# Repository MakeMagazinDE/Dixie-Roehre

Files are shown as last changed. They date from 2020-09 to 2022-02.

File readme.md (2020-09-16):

GitHub Logo

Maker Media GmbH
*** 

# Dixie-Röhre
TFT-Displays im Stil von Nixie-Röhren

### Dieser „Röhre“ dienen kleine TFT-Displays als Basis

Die „Dixie-Röhren“ werden mit einem Arduino Nano als Uhr betrieben. Sie sind in ein Holzgehäuse im Retrostil gebaut, in dem auch die überschaubare Steuerelektronik Platz findet. Zum Einstellen der Uhr sind drei Taster eingebaut. Mit einem SD-Karten-Shield und einer SD-Karte lassen sich die Bilder austauschen und für die Spannungsversorgung der Displays ist noch ein Spannungsregler nötig.

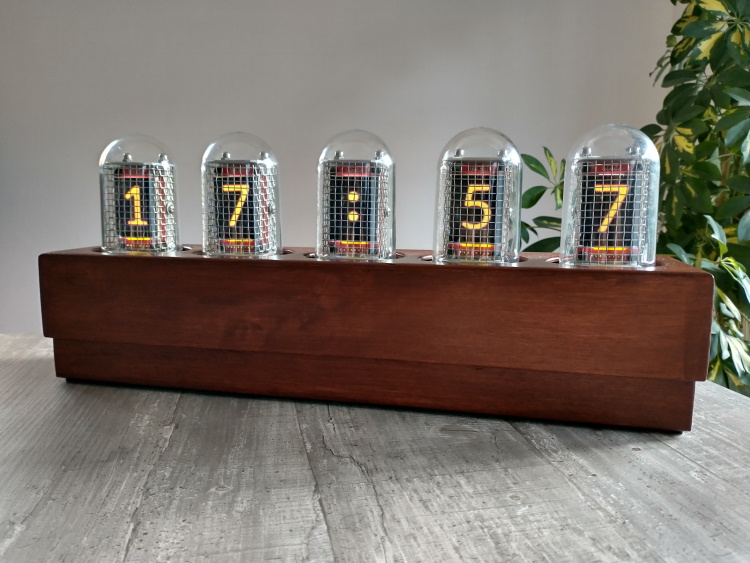
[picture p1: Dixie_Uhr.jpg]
 

Den vollständigen Artikel mit der Bauanleitung gibt es in der [Make-Ausgabe 5/2020](https://www.heise.de/select/make/2020/5/seite-46) zu lesen.

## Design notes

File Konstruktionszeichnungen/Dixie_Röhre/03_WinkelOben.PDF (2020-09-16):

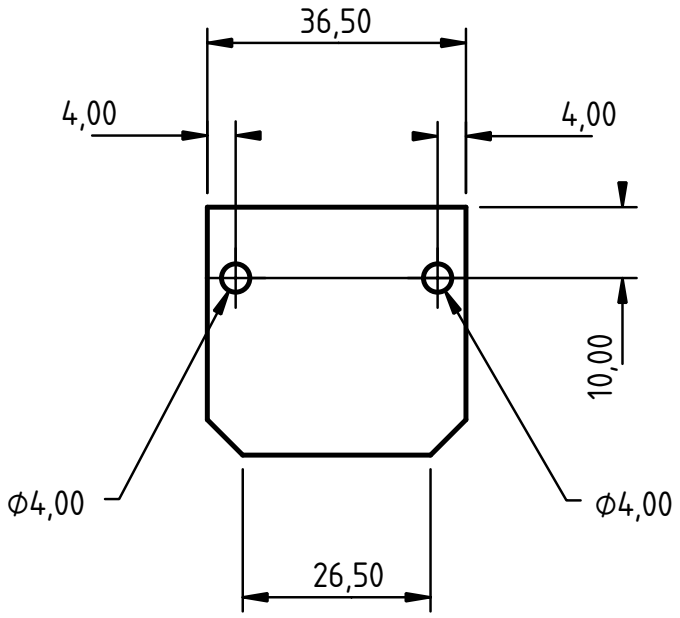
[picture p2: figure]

3

0,0

0

3

5,0

0

20,00

# Dixie-Röhre

Material: Aluminium-Winkelprofil 20mmx35mm Stärke 2mm

# 1 Stück Winkel Oben

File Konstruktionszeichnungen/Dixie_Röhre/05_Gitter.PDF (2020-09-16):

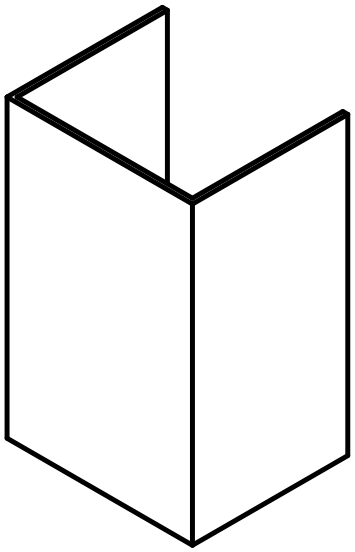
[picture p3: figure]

# Dixie-Röhre

# Gitter

Material: Drahtgitter Stärke 1mm

## 1 Stück

5

9,0

0

31,00 | 37,00

35,00

3

0,0

0

3

1,0

0

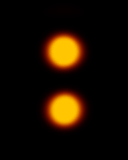
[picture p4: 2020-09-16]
Software/SD_Card_Pictures/DOT.bmp

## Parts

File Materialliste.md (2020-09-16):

# Dixie-Röhren

## Materialliste

### Material für eine Röhre
- [ ] 1× [Kunststoff-Glocke mit Untersetzer](https://www.opitec.de/basics/floristik/gefaesse/kunststoff--/kunststoff-glocke-mit-untersetzer-67-x-102-mm.html) 67 × 102mm 
- [ ] Acryl-Buntlack, Farbe: grau
- [ ] 2×  [Aluminium Quadratrohr](https://www.bauhaus.info/metallprofile-kunststoffprofile/kantoflex-quadratrohr/p/10521778) 7,5mm × 7,5mm, Stärke 1mm; 60mm lang
- [ ] 2× [Aluminium Winkelprofil](https://www.bauhaus.info/metallprofile-kunststoffprofile/kantoflex-winkelprofil/p/10520119) 20mm ×35mm, Stärke 2mm; 36,5mm lang                                  
- [ ] 2× Gewindestange M4; 90mm lang 
- [ ] 4× Mutter M4
- [ ] 2× Hutmutter M4
- [ ] 2× Federscheibe M4
- [ ] 2× Unterlegscheibe M4
- [ ] 4× [Nylon-Abstandshalter M3](https://www.amazon.de/gp/product/B00W79JXFA/), 7mm
- [ ] 4× Nylon-Schrauben M3
- [ ] 1× [SPI TFT Display 1,8 Zoll](https://www.amazon.de/gp/product/B078J5TS2G/) mit 128 × 160 Pixeln, ST7735 Bildcontroller
- [ ] 8× Farbige Kupferlitze, Querschnitt ca. 0,14 mm²; ca. 100mm lang
- [ ] 8× [Büschel/Bananen-Stecker](https://www.amazon.de/gp/product/B07S6MVTNQ/), 4mm
- [ ] 1× [Drahtgitter](https://www.amazon.de/gp/product/B07ZSS4ZQ6/), ca. 59mm × 93mm 
- [ ] 2× Unterlegscheibe M3
- [ ] 2× Schraube M3x4mm

### Elektronik
- [ ] 1× [Steckbrett mit „Jumper“-Kabeln](https://www.amazon.de/dp/B07NJ3FX25/)
- [ ] 1× Arduino Nano
- [ ] 1× [Arduino SD-Karten Shield](https://www.amazon.de/gp/product/B077MB17JB/) 
- [ ] SD-Karte (FAT32-formatiert)
- [ ] 1× Lochrasterplatine 2,54mm, 7×5 cm 
- [ ] Kupferdraht, verzinnt; Stärke ca. 0,4mm; 
- [ ] Stiftleisten und Buchsenleisten im Raster 2,54mm
- [ ] 6× Widerstände 10k
- [ ] 3× Kondensator 10nF; Elektrolytkondensatoren 1× 100nF und 1× 10µF 
- [ ] 1× Spannungsregler 3,3V (LD33V)
- [ ] 3× [Drucktaster mit Schließer-Kontakt](https://www.amazon.de/gp/product/B07Q6YPST6/)
- [ ] 1× USB-B Buchse
- [ ] 40× [Buchsen für Bananen-Stecker](https://www.amazon.de/gp/product/B07VWQQRHC/)

### Gehäuse
- [ ] Sperrholzplatten (Größe min. A3)
- [ ] Vierkanthölzer (ca. 9x9mm)
- [ ] Holzleim 
- [ ] Möbelversiegelung oder Buntlack, Farbe: z.B. Teak

## Werkzeug
- [ ] Metallsäge
- [ ] Laubsäge
- [ ] Feile(n) und Schleifpapier
- [ ] Akkuschrauber oder Bohrmaschine, Bohrer 
- [ ] Kegel-Senker und ein M3 Gewindeschneider, Flach-Senker (oder Forstnerbohrer)
- [ ] Schraubstock, Schraubzwingen
- [ ] Lötkolben
- [ ] Diverse Handwerkzeuge (Seitenschneider, Schraubendreher, Ringschlüssel)
- [ ] Teppichmesser oder Cutter-Messer
- [ ] Durchgangsprüfer oder Handmultimeter

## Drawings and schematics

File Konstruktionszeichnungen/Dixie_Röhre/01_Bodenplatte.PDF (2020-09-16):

# Dixie-Röhre

# 1 Stück

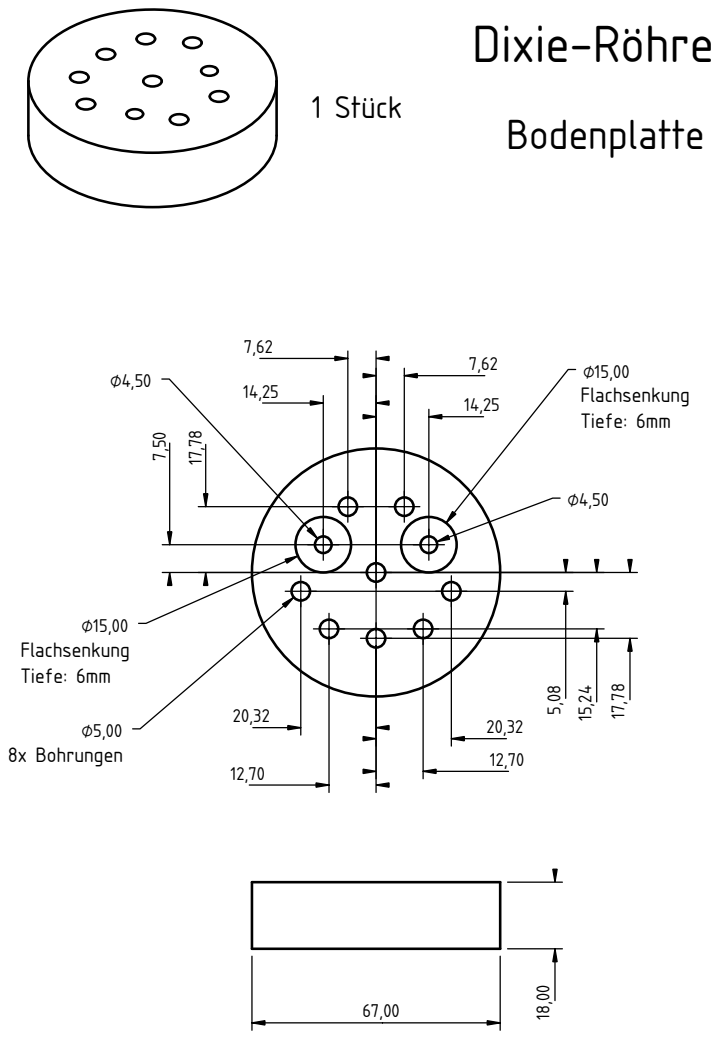
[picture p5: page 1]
Flachsenkung Tiefe: 6mm; 8x Bohrungen; Bodenplatte

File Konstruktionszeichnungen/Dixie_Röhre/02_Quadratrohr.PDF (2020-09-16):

# Dixie-Röhre

## 2 Stück

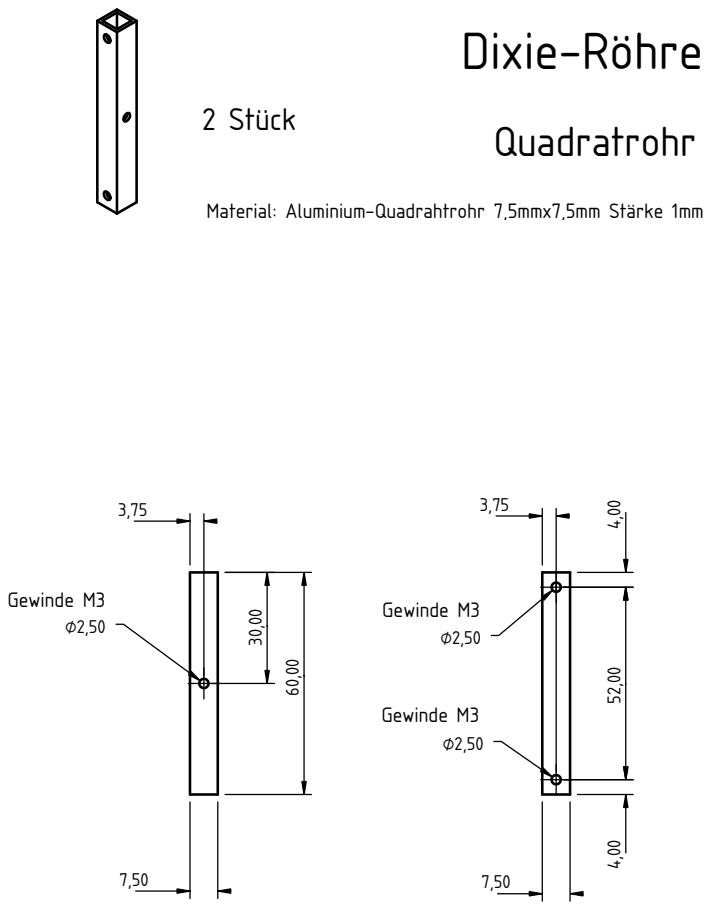
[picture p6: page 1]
Gewinde M3; Quadratrohr

Material: Aluminium-Quadrahtrohr 7,5mmx7,5mm Stärke 1mm

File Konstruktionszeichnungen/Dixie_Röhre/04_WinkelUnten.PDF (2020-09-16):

# Dixie-Röhre

# 1 Stück Winkel Unten

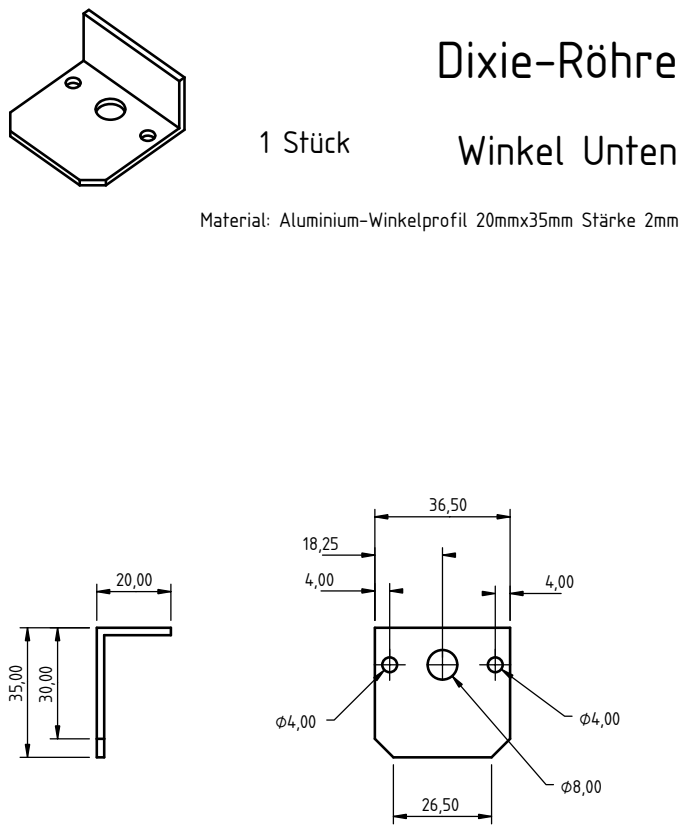
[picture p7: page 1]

Material: Aluminium-Winkelprofil 20mmx35mm Stärke 2mm

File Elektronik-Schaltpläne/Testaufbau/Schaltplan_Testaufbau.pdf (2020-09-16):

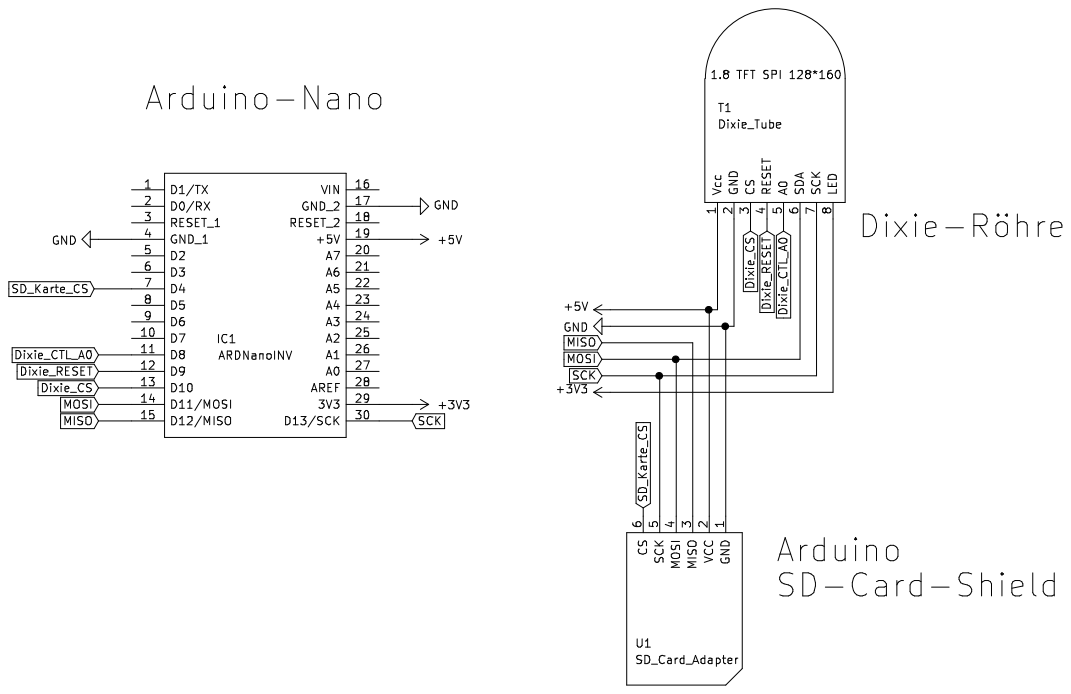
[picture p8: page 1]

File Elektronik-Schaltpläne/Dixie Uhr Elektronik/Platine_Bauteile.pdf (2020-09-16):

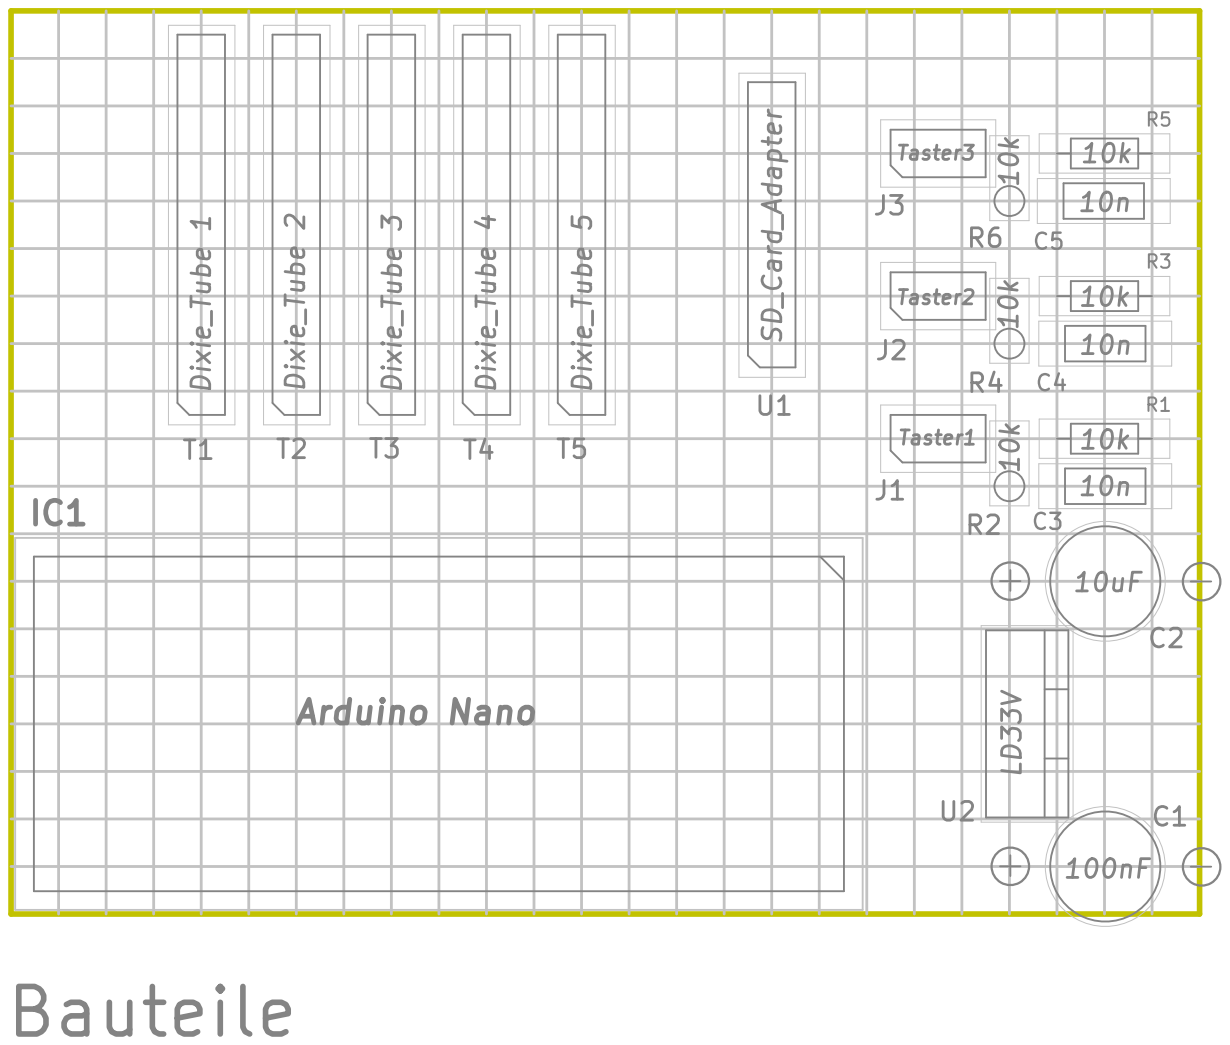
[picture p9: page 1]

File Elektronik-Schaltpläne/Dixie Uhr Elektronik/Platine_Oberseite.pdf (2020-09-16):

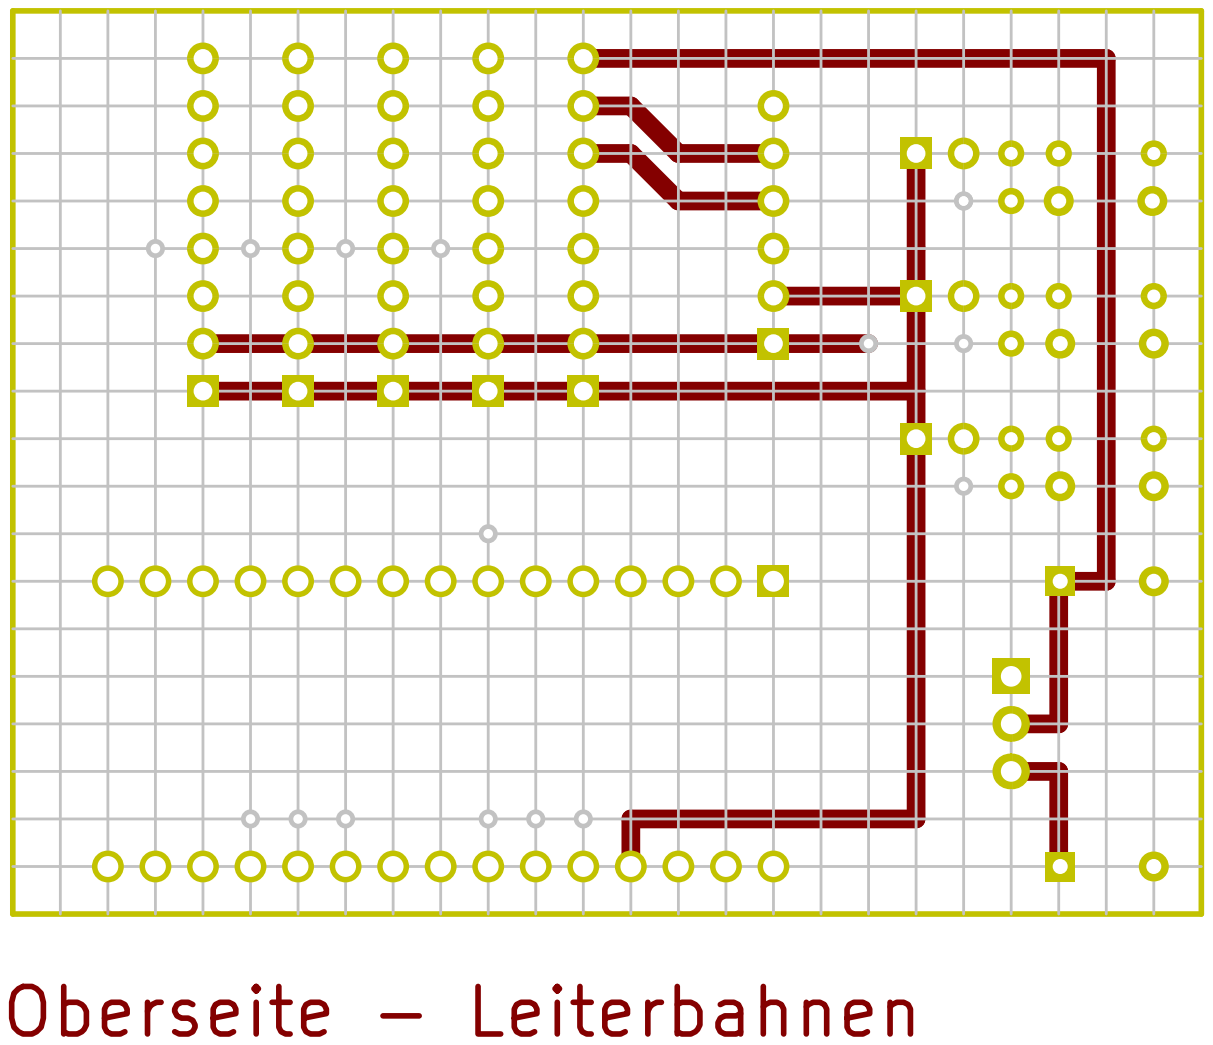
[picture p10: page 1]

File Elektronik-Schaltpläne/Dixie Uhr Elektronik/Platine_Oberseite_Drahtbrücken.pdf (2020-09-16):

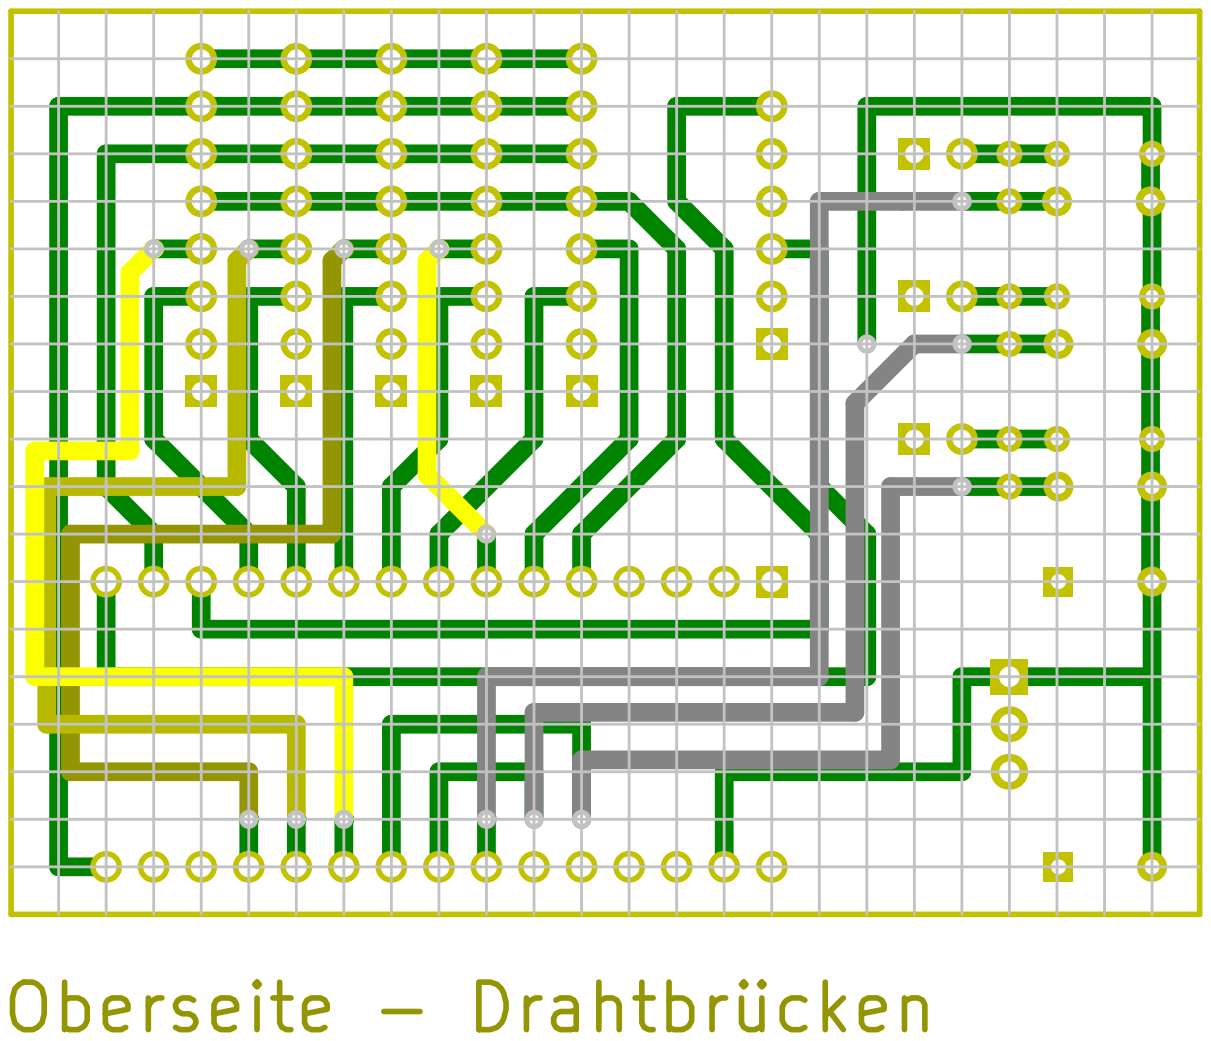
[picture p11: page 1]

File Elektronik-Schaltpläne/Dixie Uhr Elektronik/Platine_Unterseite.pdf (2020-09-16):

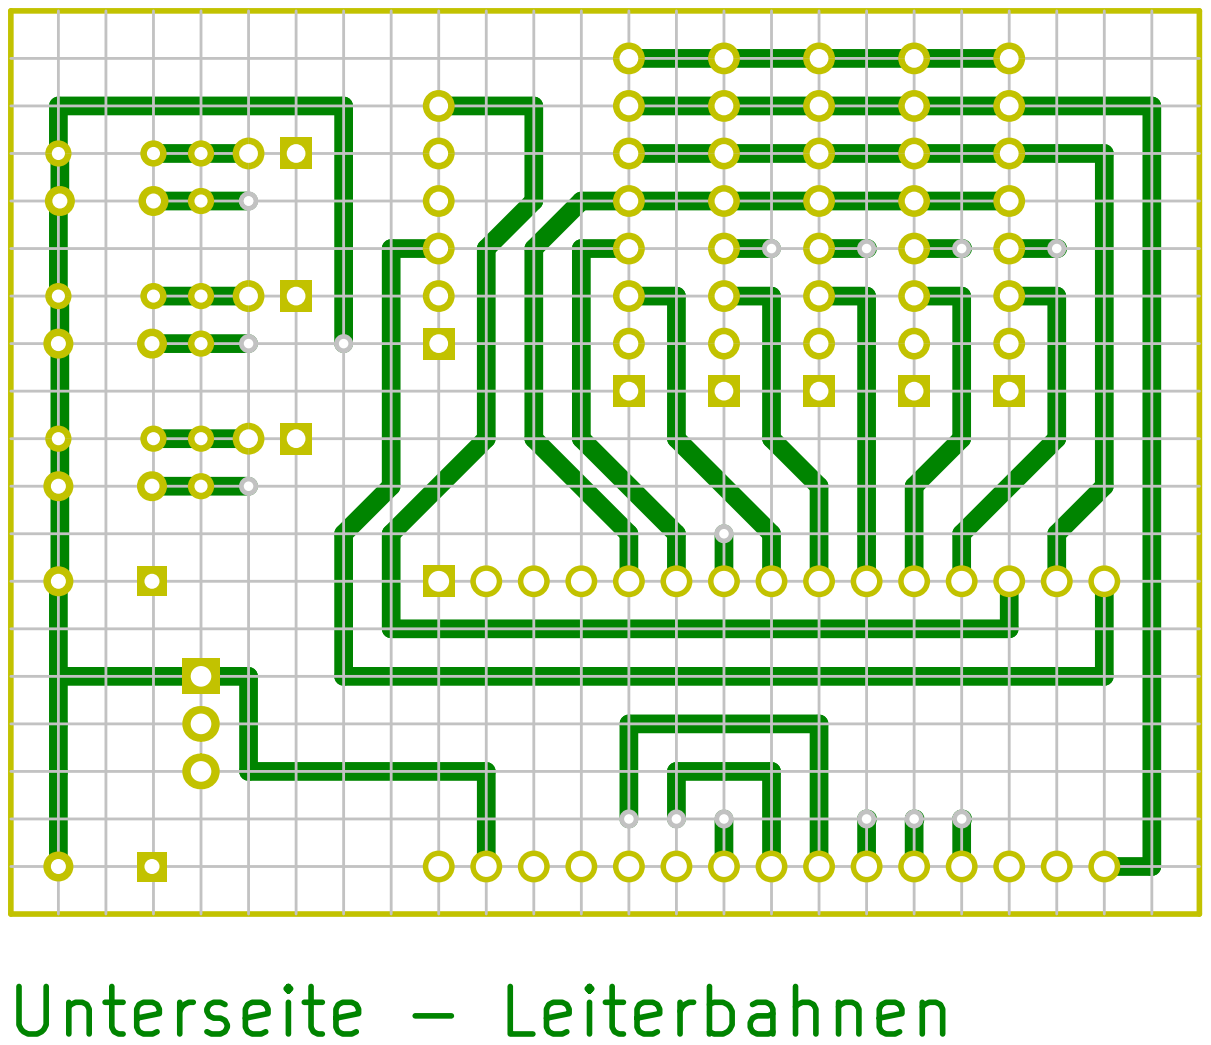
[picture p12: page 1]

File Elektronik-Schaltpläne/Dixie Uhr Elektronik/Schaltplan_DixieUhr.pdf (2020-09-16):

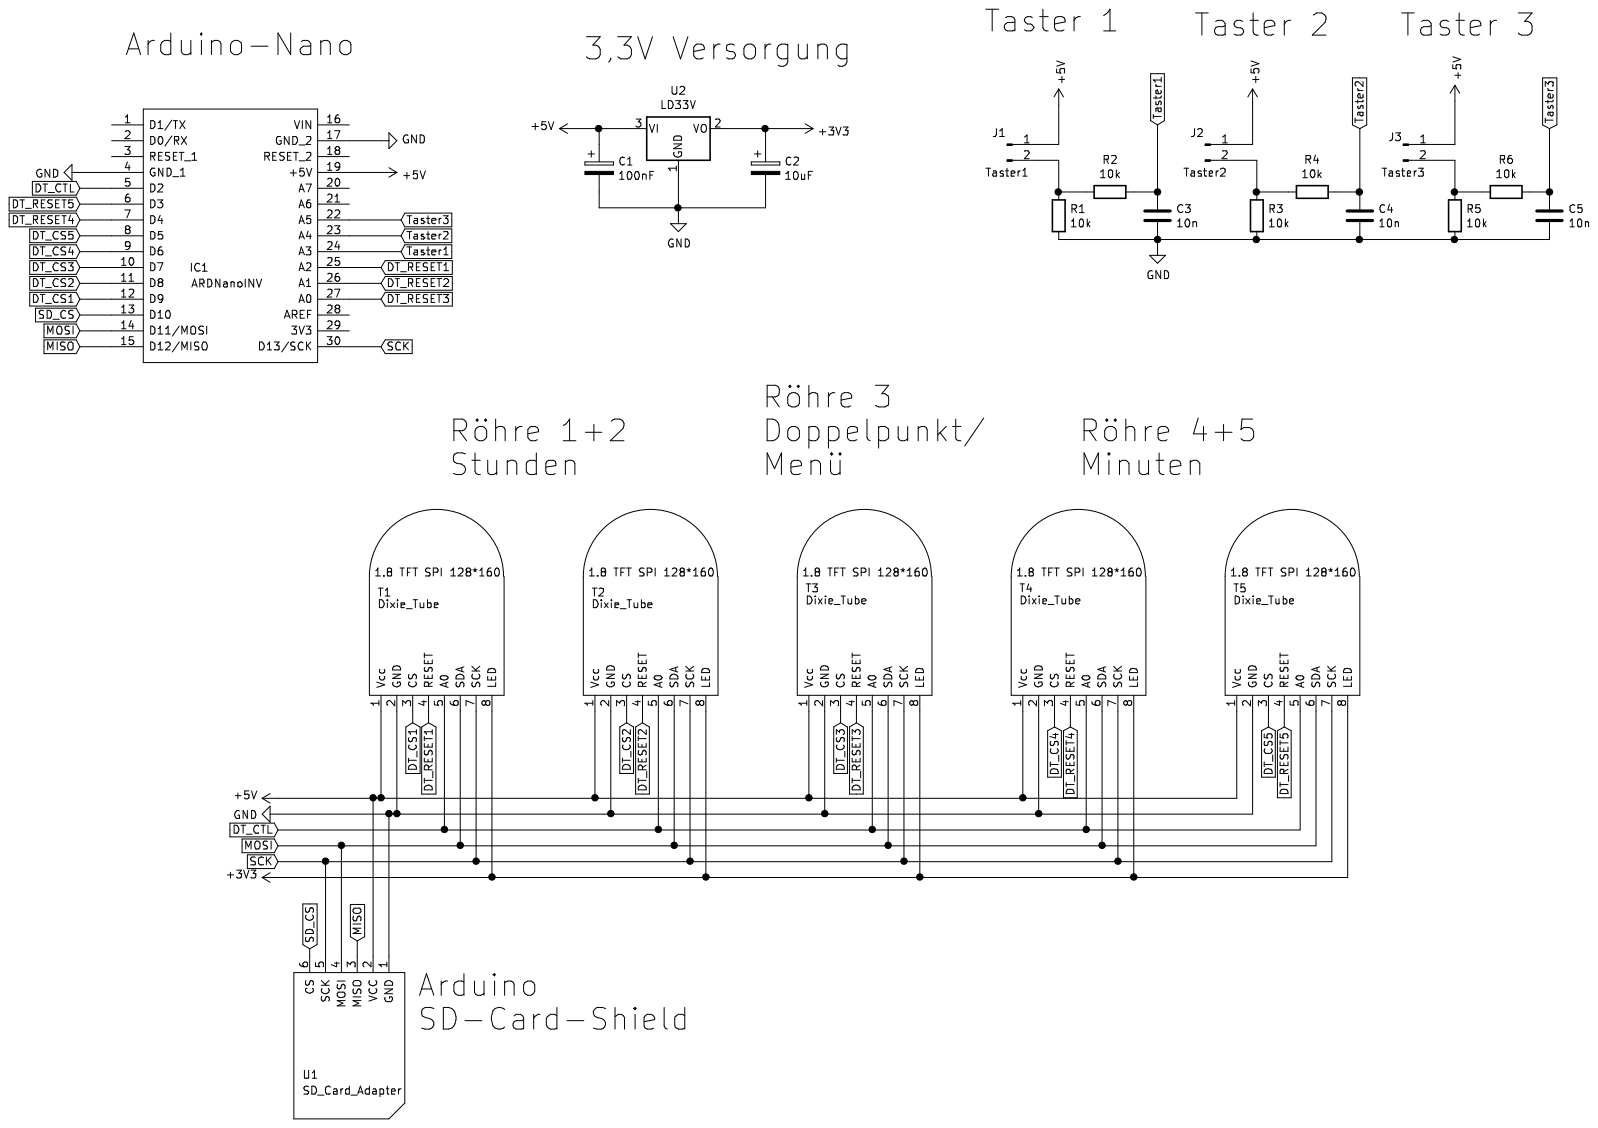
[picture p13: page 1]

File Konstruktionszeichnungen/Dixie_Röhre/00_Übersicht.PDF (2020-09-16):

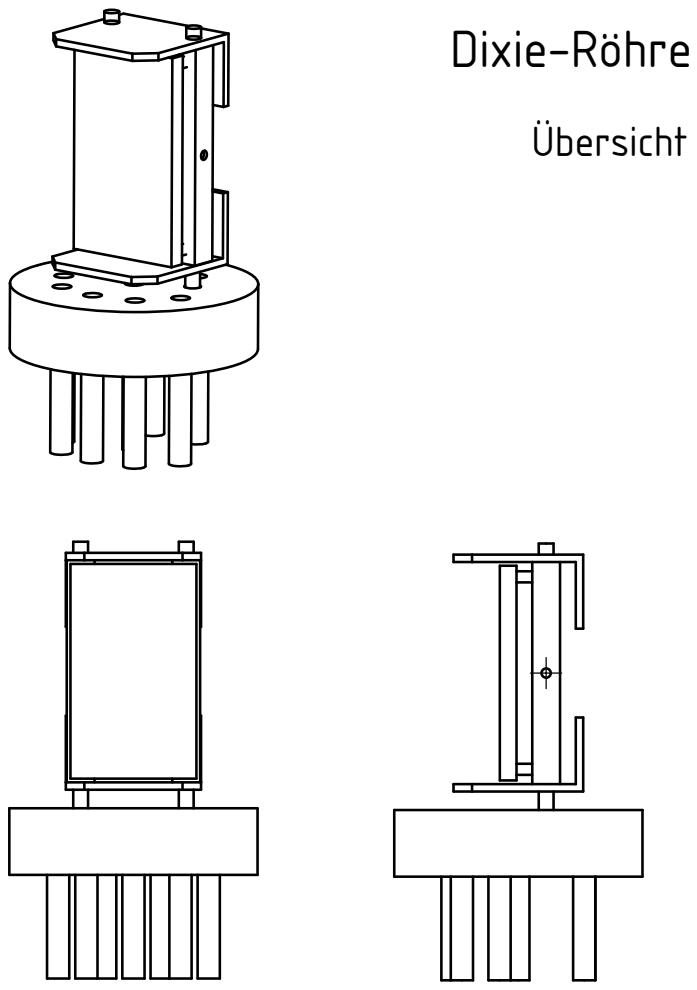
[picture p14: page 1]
Dixie-Röhre; Übersicht

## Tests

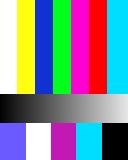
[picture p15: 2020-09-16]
Software/SD_Card_Pictures/Testbild.bmp

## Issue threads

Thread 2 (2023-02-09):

Funktion Taster 1 in der RTC Version ?

db1966, 2023-02-09:
Hi,
Ich habe die Uhren-Elektrionik gerade nachgebaut, als RTC Version. Allerdings erschließt sich mir die Funktion des Tasters #1 nicht. Der wird zwar explizit als Input und Low definiert (D17) aber im Code nicht mehr abgefragt, Dementsprechend passiert auch nix, wenn man drauf drückt ... Ist der Taster vergessen worden ? Datumsanzeige auf Knopfdruck wäre schön...

Ist das schonmal aufgefallen, ist das ggf schon gelöst worden ?

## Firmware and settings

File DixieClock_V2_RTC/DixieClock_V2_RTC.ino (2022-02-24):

//----------------------------------------------------------------------------------------------------------------------------------------------------------------------
//   ________________________________________________________
//   R E A L   T I M E
//   ###   #  #   #  #  ####      ###  #      ##    ###  #  #
//   #  #  #   # #   #  #        #     #     #  #  #     # #
//   #  #  #    #    #  ###      #     #     #  #  #     ##
//   #  #  #   # #   #  #        #     #     #  #  #     # #
//   ###   #  #   #  #  ####      ###  ####   ##    ###  #  #
//   ________________________________________________________
//
//   Dixie Clock - Version 2.00 
//   M2theH - October 02, 2021
//   
//   Required hardware changes:
//   - Remove push button 2 (Pin A4) and push button 3 (Pin A5) and the associated resistors and capacitors.
//   - Connect the RTC-Shield-DS3231 to the Arduino via I2C (Pin A4->SDA and Pin A5->SCL).
//
//   Info: To use the RTC-Shield, an initialization of the time is necessary.  
//         Therefore the example "interactive" from the libary ds3231FS can be used. 
//
//----------------------------------------------------------------------------------------------------------------------------------------------------------------------


// __ Libraries ________________________________________________________________________________________________________________________________________________________

#include <Adafruit_GFX.h>                                         // Core graphics library
#include <Adafruit_ST7735.h>                                      // Hardware-specific library
#include <SdFat.h>                                                // SD card & FAT filesystem library
#include <Adafruit_SPIFlash.h>                                    // SPI / QSPI flash library
#include <Adafruit_ImageReader.h>                                 // Image-reading functions
#include <TimerOne.h>                                             // Timer functions
#include <Wire.h>                                                 // I2C libary
#include <ds3231.h>                                               // DS3231 Real Time Clock libary "ds3231FS" 

// __ Pins ______________________________________________________________________________________________________________________________________________________________

#define SD_CS    10                                               // SD Card chip select; pin D10
#define TFT1_CS  9                                                // TFT No.1 chip select; pin D9
#define TFT2_CS  8                                                // TFT No.2 chip select; pin D8
#define TFT3_CS  7                                                // TFT No.3 chip select; pin D7
#define TFT4_CS  6                                                // TFT No.4 chip select; pin D6
#define TFT5_CS  5                                                // TFT No.5 chip select; pin D5
#define TFT1_RST  16                                              // TFT No.1 RESET; pin D16 (A2)
#define TFT2_RST  15                                              // TFT No.2 RESET; pin D15 (A1)
#define TFT3_RST  14                                              // TFT No.3 RESET; pin D14 (A0) 
#define TFT4_RST  4                                               // TFT No.4 RESET; pin D4
#define TFT5_RST  3                                               // TFT No.5 RESET; pin D3
#define TFT_DC   2                                                // TFT A0 display/command; pin D2

// __ Variables and Flags _______________________________________________________________________________________________________________________________________________

struct ts t;                                                      // ts is a struct findable in ds3231.h

int Count500ms = 0;                                               // Counter 500ms
int DoAction_500ms = 0;                                           // 1 = Do action every 500ms
int UpdateDisplayMin = 1;                                         // 1 = Update tubes - minutes
int UpdateDisplayHour = 1;                                        // 1 = Update tubes - hours

int SEC = 0;                                                      // Seconds
int MIN = 0;                                                      // Minutes
int HOUR = 0;                                                     // Hours

char DixieSec [10];                                               // Buffer for seconds
char DixieMin [10];                                               // Buffer for Minutes
char DixieMin1 [10];                                              // Buffer for time output tube 1
char DixieMin2 [10];                                              // Buffer for time output tube 2
char DixieHour [10];                                              // Buffer for Hours
char DixieHour1 [10];                                             // Buffer for time output tube 3
char DixieHour2 [10];                                             // Buffer for time output tube 4
char Endung [10] = ".bmp";                                        // File format of pictures on SD card

// __ Display and SD Card _______________________________________________________________________________________________________________________________________________

SdFat                SD;                                          // SD card filesystem
Adafruit_ImageReader reader(SD);                                  // Image-reader object, pass in SD filesystem

Adafruit_ST7735 tft1 = Adafruit_ST7735(TFT1_CS, TFT_DC, TFT1_RST);// display 1 Hours
Adafruit_ST7735 tft2 = Adafruit_ST7735(TFT2_CS, TFT_DC, TFT2_RST);// display 2 Hours
Adafruit_ST7735 tft3 = Adafruit_ST7735(TFT3_CS, TFT_DC, TFT3_RST);// display 3 Dot/Menu
Adafruit_ST7735 tft4 = Adafruit_ST7735(TFT4_CS, TFT_DC, TFT4_RST);// display 4 Minutes
Adafruit_ST7735 tft5 = Adafruit_ST7735(TFT5_CS, TFT_DC, TFT5_RST);// display 5 Minutes


// #####################################################################################################################################################################                     
// #### HW Setup #######################################################################################################################################################
// #####################################################################################################################################################################


void setup(void) 
{
  // __ Initialize I2C __________________________________________________________________________________________________________________________________________________

  Wire.begin();                                                   // Begin I2C bus 
  
  // __ Initialize Real Time Clock ______________________________________________________________________________________________________________________________________

  DS3231_init(DS3231_INTCN);                                      // Register the ds3231 (DS3231_INTCN is the default address of ds3231)
  
  // __ Initialize analog pins as digital input _________________________________________________________________________________________________________________________

  pinMode(A3,INPUT);                                              // Analog Pin 3 >> Digital 17 - Button
  digitalWrite(17,LOW);                                           // AActivate pulldown
  
  // __ Initialize serial communication _________________________________________________________________________________________________________________________________

  Serial.begin(9600);                                             // Initialize serial
  
  // __ Initialize SD-FAT Filesystem before using image reader functions ________________________________________________________________________________________________ 

  if(!SD.begin(SD_CS, SD_SCK_MHZ(10)))            
    { 
      Serial.println("SD Card ERROR");                            // Info message - initialization error
      for(;;);                                    
    }

  // __ Initialize Interrupt Timer1 _____________________________________________________________________________________________________________________________________

  Timer1.initialize(1000);                                        // Interrupt every 1ms (1000us)
  Timer1.attachInterrupt(Interrupt);                              // call interrupt function

  // __ Initialize Displays/Tubes _______________________________________________________________________________________________________________________________________
  
  tft1.initR(INITR_BLACKTAB);                                     // Initialize Display 1
  tft1.fillScreen(ST7735_BLACK);                                  // Fill display - color black
  
  tft2.initR(INITR_BLACKTAB);                                     // Initialize Display 2
  tft2.fillScreen(ST7735_BLACK);                                  // Fill display - color black
  
  tft3.initR(INITR_BLACKTAB);                                     // Initialize display 3
  tft3.fillScreen(ST7735_BLACK);                                  // Fill display - color black
  
  tft4.initR(INITR_BLACKTAB);                                     // Initialize Display 4
  tft4.fillScreen(ST7735_BLACK);                                  // Fill display - color black
  
  tft5.initR(INITR_BLACKTAB);                                     // Initialize display 5
  tft5.fillScreen(ST7735_BLACK);                                  // Fill display - color black

  reader.drawBMP("/DOT.bmp", tft3, 0, 0);                         // Load colon picture into display/tube

  Serial.println("Initialization OK");
}


// #####################################################################################################################################################################
// #### Interrupt function #############################################################################################################################################
// #####################################################################################################################################################################


void Interrupt(void)                                              // This function is called every 1ms              
{
  Count500ms++;

  if (Count500ms == 500)
    { 
      DoAction_500ms = 1;                                         // Flag to perform actions in main loop every 500ms
      Count500ms = 0;
    }
}


// #####################################################################################################################################################################
// #### Functions ######################################################################################################################################################
// #####################################################################################################################################################################


void ReadRTC(void)
{ 
  DS3231_get(&t);                                                 // Get the value and pass to the function the pointer to t
                                                                  
  SEC = t.sec;                                                    // Transfer value to variable - Seconds
  MIN = t.min;                                                    // Transfer value to variable - Minutes
  HOUR = t.hour;                                                  // Transfer value to variable - Hours

  if(SEC == 0)               { UpdateDisplayMin  = 1; }           // Check if a minute has passed
  if((SEC == 0)&&(MIN == 0)) { UpdateDisplayHour = 1; }           // Check if an hour has passed
}

// ----------------------------------------------------------------------------------------------------------------------------------------------------------------------

void BuildFilenameMinutes(void)
{ 
    sprintf(DixieMin,"%02u", MIN);
    sprintf(DixieMin1, "%c%s", DixieMin[0], Endung);              // Build file name on SD card D0X.bmp -> X = number
    sprintf(DixieMin2, "%c%s", DixieMin[1],Endung);               // Build file name on SD card D0X.bmp -> X = number
}

// ----------------------------------------------------------------------------------------------------------------------------------------------------------------------

void BuildFilenameHours(void)
{ 
    sprintf(DixieHour,"%02u", HOUR);
    sprintf(DixieHour1, "%c%s", DixieHour[0],Endung);             // Build file name on SD card D0X.bmp -> X = number
    sprintf(DixieHour2, "%c%s", DixieHour[1],Endung);             // Build file name on SD card D0X.bmp -> X = number
}

// ----------------------------------------------------------------------------------------------------------------------------------------------------------------------

void WriteTubeMinutes (void)                                      // Write actual time - minutes into displays/tubes
{
    reader.drawBMP(DixieMin1, tft4, 0, 0);                        // Load number/picture into the tube 4
    reader.drawBMP(DixieMin2, tft5, 0, 0);                        // Load number/picture into the tube 5
}   

// ----------------------------------------------------------------------------------------------------------------------------------------------------------------------

void WriteTubeHours (void)                                        // Write actual time - hours into displays/tubes
{
    reader.drawBMP(DixieHour1, tft1, 0, 0);                       // Load number/picture into the tube 1
    reader.drawBMP(DixieHour2, tft2, 0, 0);                       // Load number/picture into the tube 2
}


// #####################################################################################################################################################################
// #### Main function ##################################################################################################################################################
// #####################################################################################################################################################################


void loop() 
{

  if (DoAction_500ms == 1)                                        // Perform actions every 500ms
    {
      ReadRTC();                                                  // Get time from ds3231
      BuildFilenameHours();                                       // Build filenames of pictures on SD card - Hours
      BuildFilenameMinutes();                                     // Build filenames of pictures on SD card - Minutes
       
      DoAction_500ms = 0;   
    }

//---------------------------------------------------------------------------------------------------------------------------------------------------------------------

  if (UpdateDisplayMin)                                           // This flag is set in fuction ReadRTC()
  {
    WriteTubeMinutes();                                           // Write actual minutes into displays/tubes

//    Serial.print("Time: ");                                       // Output time on serial
//    Serial.print(HOUR);                                           // Hours
//    Serial.print(":");                                            //
//    Serial.println(MIN);                                          // Minutes
    
    UpdateDisplayMin = 0;
  }

//--------------------------------------------------------------------------------------------------------------------------------------------------------------------- 

  if (UpdateDisplayHour)                                          // This flag is set in fuction ReadRTC()
  {   
    WriteTubeHours();                                             // Write actual hours into displays/tubes
   
    UpdateDisplayHour = 0;
  }

}
